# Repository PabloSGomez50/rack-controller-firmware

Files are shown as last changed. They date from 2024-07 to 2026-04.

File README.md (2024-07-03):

# Sistema de Monitoreo y Control IoT para Rack de Telecomunicaciones

Este repositorio contiene el código fuente y la documentación para un dispositivo de monitoreo y control desarrollado para un proveedor de internet. El dispositivo se diseñó para ser instalado en un rack de telecomunicaciones Huawei y se comunica a través de Ethernet para monitorear condiciones ambientales y controlar componentes del rack.

https://github.com/nicolasottone/rack-controller-firmware/assets/64184394/97a96b82-3d05-4193-a270-a76540e8a40f

## Resumen

Se consume la API REST de Google Firebase desde el microcontrolador ESP32 para enviar y recibir datos mediante HTTPS. Desde una aplicación web se accede a los mismos en tiempo real y se controla el dispositivo a distancia. 

**Características:**

* **Monitoreo:**
    * Temperatura ambiental y de contacto.
    * Humedad relativa.
    * Presencia de humo.
    * Estado de la puerta del rack (abierta/cerrada).
* **Control:**
    * 3 ventiladores con control PWM y tacometría.
    * Un relé para control remoto de periféricos.
    * Buzzer para alertas locales.
* **Comunicación:**
    * Conexión Ethernet a través de un módulo ENC28J60.
    * Interfaz web para monitoreo y control remoto.
* **Integración con Firebase:**
    * Envío de datos a la Realtime Database de Firebase.
    * Uso del SDK de Firebase en el lado del cliente para recibir y enviar datos.
    * Conección en tiempo real por Websockets.
    * Autenticación de usuarios con Firebase Auth.
* **Interfaz de Usuario:**
    * Aplicación web con gráficos de datos en tiempo real, KPIs, alertas graficas y panel de configuración.
    * Control remoto de ventiladores, relé y configuración del dispositivo.
* **Hardware:**
    * Microcontrolador ESP32 con RTOS.
    * Modulo Ethernet ENC28J60.
    * Sensores de temperatura, humedad, humo y switch magnético.
    * * Sensor NTC 10K de alta precisión.
    * * Termohigrómetro WS302A1T4
    * * Sensor de Humo JTY-GD-S839
    * Protección contra polaridad inversa.
    * Etapas de acondicionamiento de señales (etapa de potencias, opto-acopladores, etc).
    * Pantalla LCD de 2x16 caracteres.
    * Fuente Step-Up de 48V, fuente Step-Down 12V y reguladores lineales 5V.
    * Conectores HOWSING.

**Arquitectura:**

* **Hardware:**
    * El hardware se basa en el ESP32, un microcontrolador de doble núcleo y ADC incorporados.
    * El módulo ENC28J60 proporciona la conectividad Ethernet.
    * Los sensores, actuadores y periféricos se conectan al ESP32 a través de interfaces GPIO.
* **Software:**
    * El software se divide en dos tareas principales, una para cada núcleo del ESP32:
        * **Núcleo 0:** Lee datos de los sensores, controla los actuadores y maneja los estados del dispositivo.
        * **Núcleo 1:** Envía y recibe datos al servidor a través de una conexión HTTPS.
    * La comunicación con el servidor se realiza mediante peticiones POST y GET a la API REST de Firebase.
    * La aplicación web utiliza WebSockets para recibir actualizaciones de datos en tiempo real.
    * La interfaz de usuario se desarrolló con HTML, CSS, JavaScript y jQuery.

**Calibración:**

* Los ADC fueron calibrados digitalmente usando un multímetro como referencia.
* El termistor NTC se calibró usando el método Steinhart-Hart.
* Se realizaron pruebas de funcionamiento de los ventiladores y se ajustó el control PWM para un óptimo desempeño.

**Niveles de Tensión:**

* El dispositivo opera internamente a 4 niveles de tensión: 48V, 12V, 5V y 3,3V.
* Se puede alimentar con un rango de tensión de 12V a 30V.

**Case:**

* Se diseño un case que consta de dos partes unidas por tornillos para proteger el dispotivo.
* Se utilizo SolidWorks y se diseño para ser impreso en 3D. 

**Documentación:**

* Este README.md proporciona una descripción general del proyecto.
* Los archivos de código fuente contienen comentarios detallados en español.
* La documentación adicional se encuentra en la carpeta `assets`. (Tambien se puede acceder al video con la calidad original).

## Assets:
### Esquema del circuito:
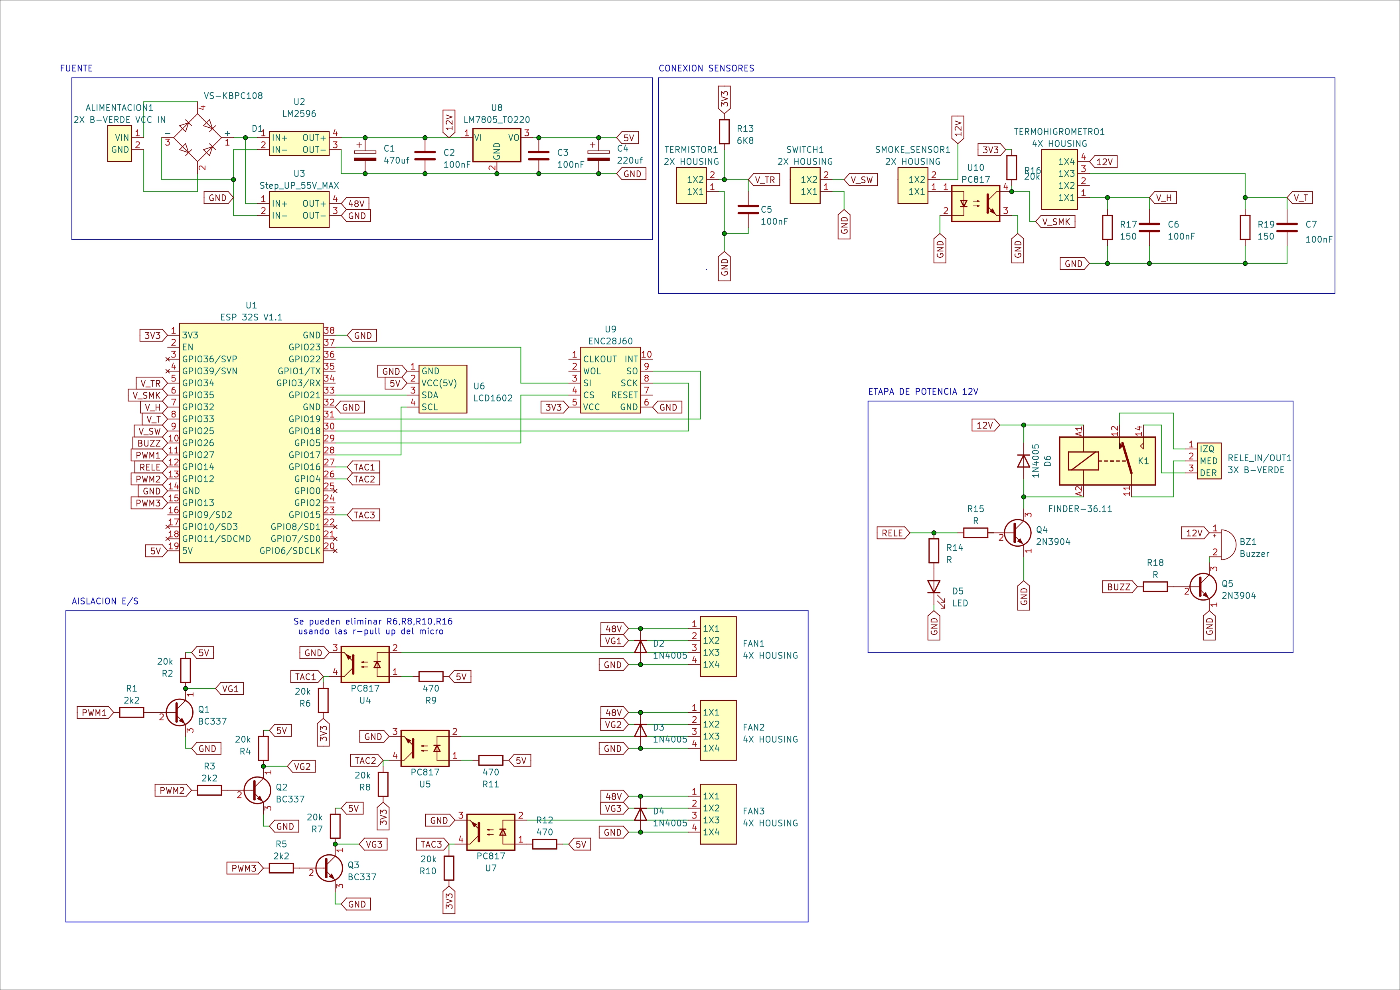
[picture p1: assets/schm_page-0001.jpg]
schm_page-0001
* 

### Imagenes del case:
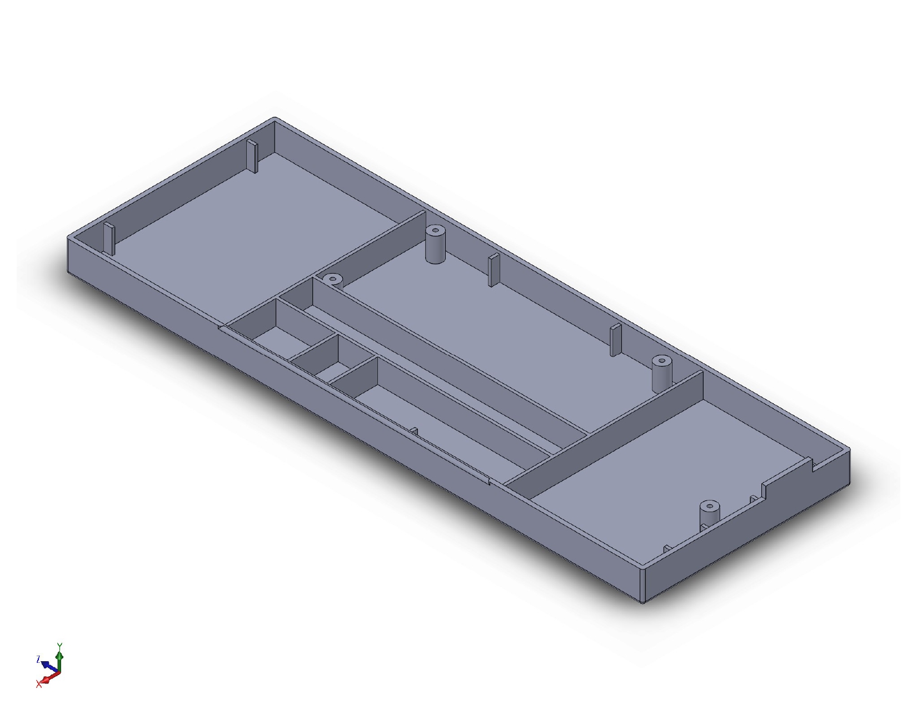
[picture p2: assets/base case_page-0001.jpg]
base case view_page-0001
* 
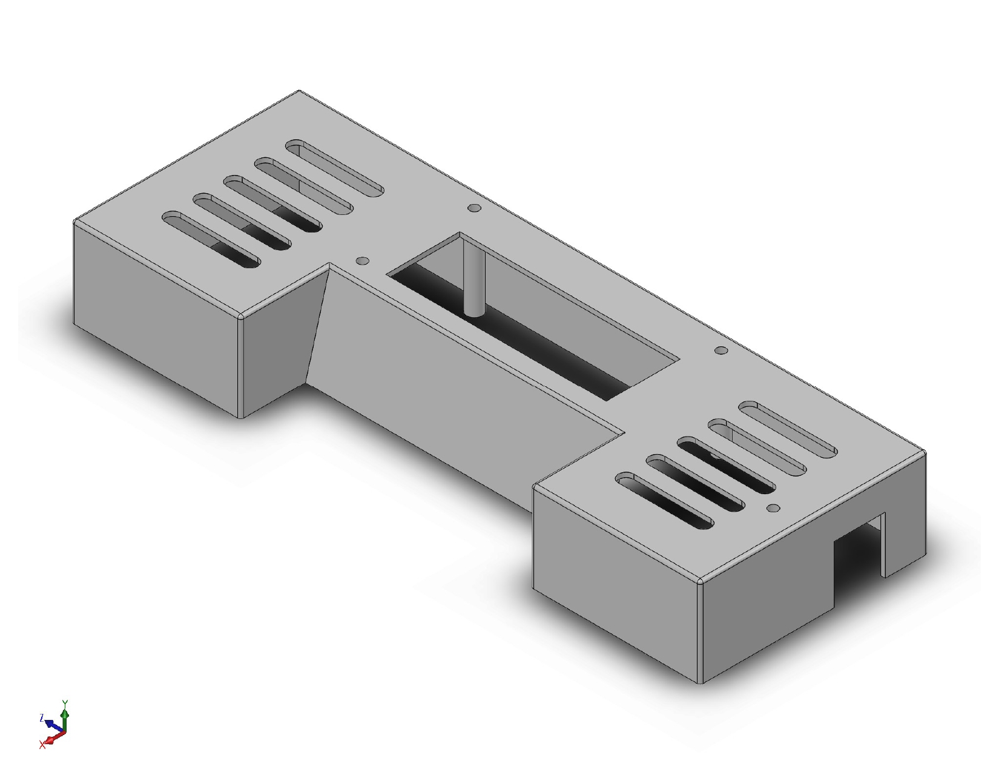
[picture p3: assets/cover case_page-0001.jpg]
cover case_page-0001
* 
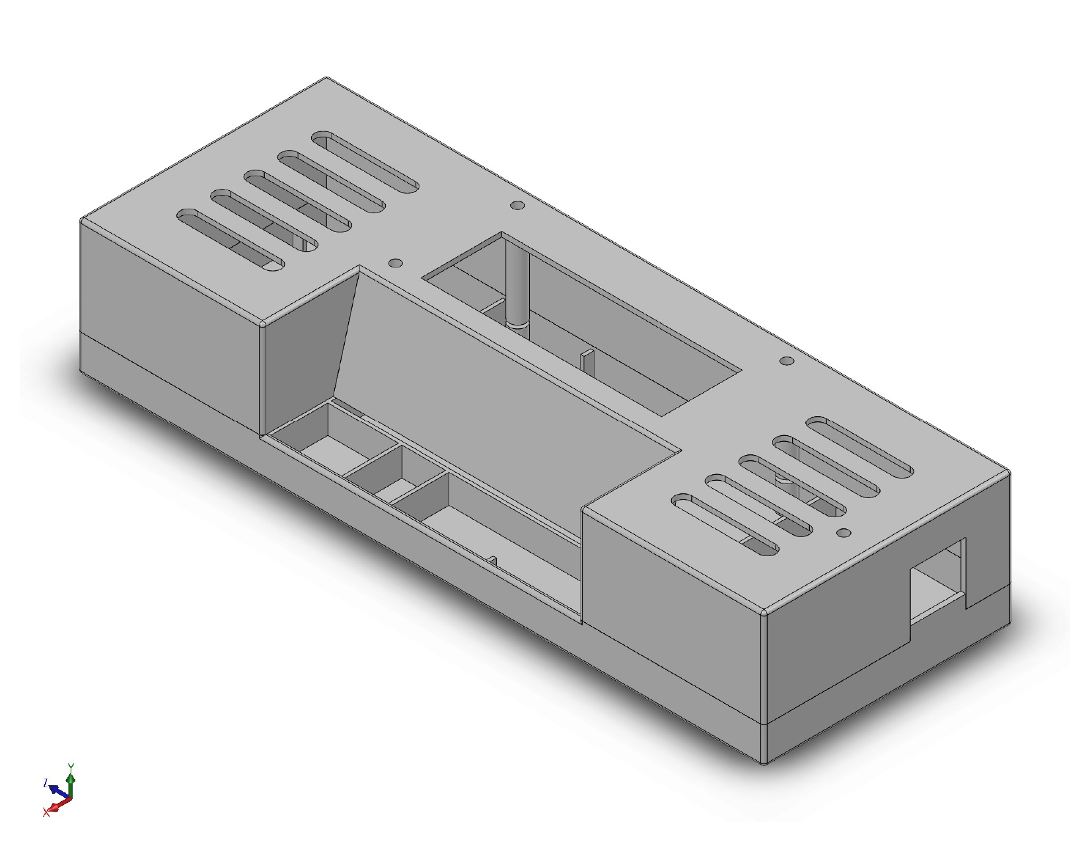
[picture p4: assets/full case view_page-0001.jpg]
full case view_page-0001
* 

### Board:
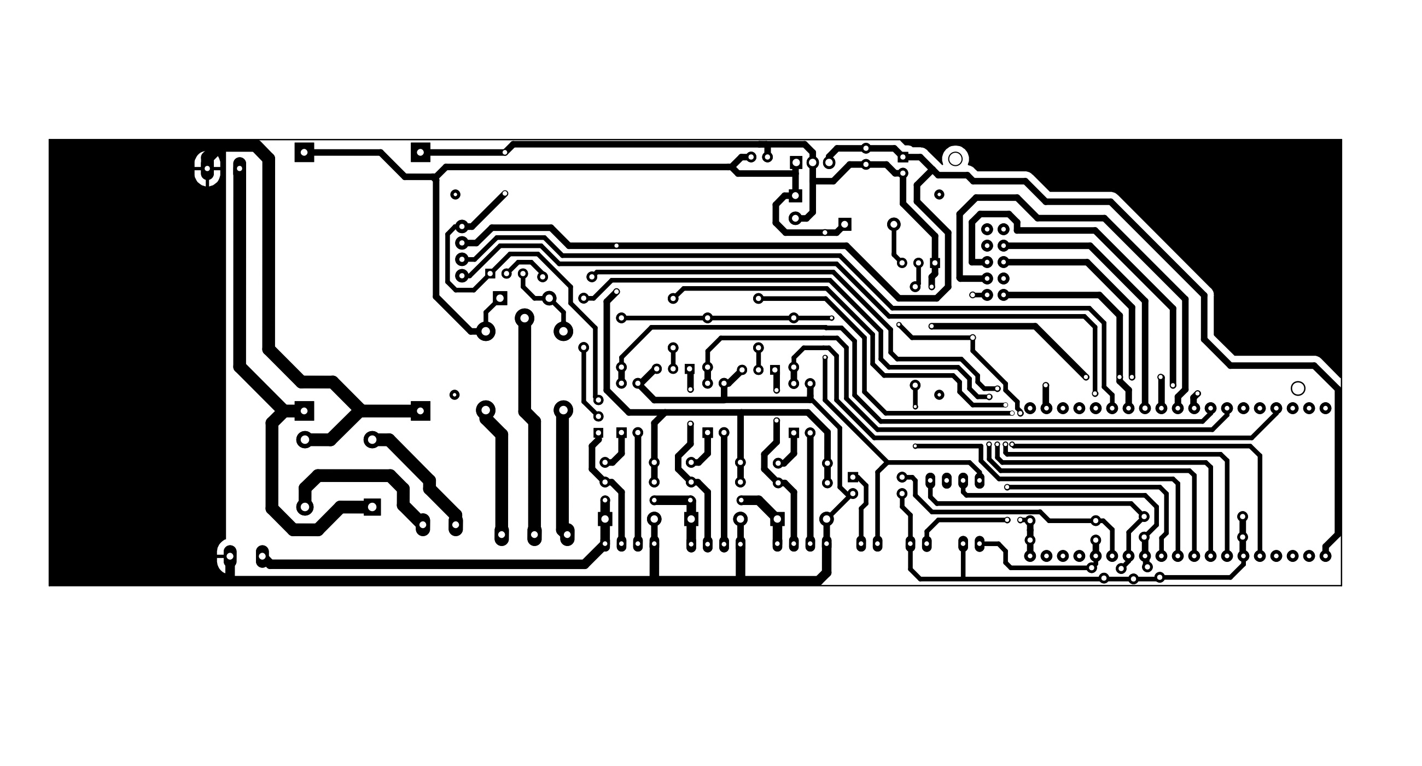
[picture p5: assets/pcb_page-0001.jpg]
pcb_page-0001
* 
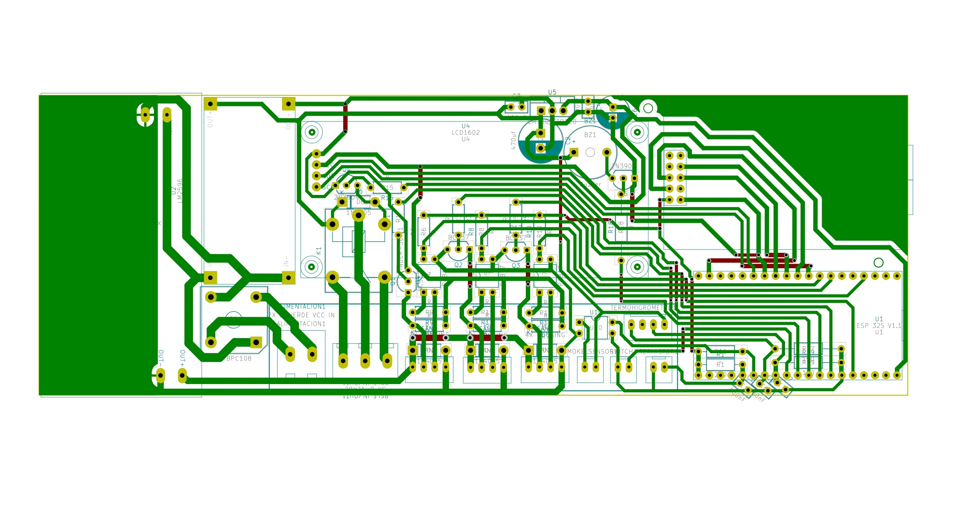
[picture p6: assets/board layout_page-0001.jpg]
board layout_page-0001
*

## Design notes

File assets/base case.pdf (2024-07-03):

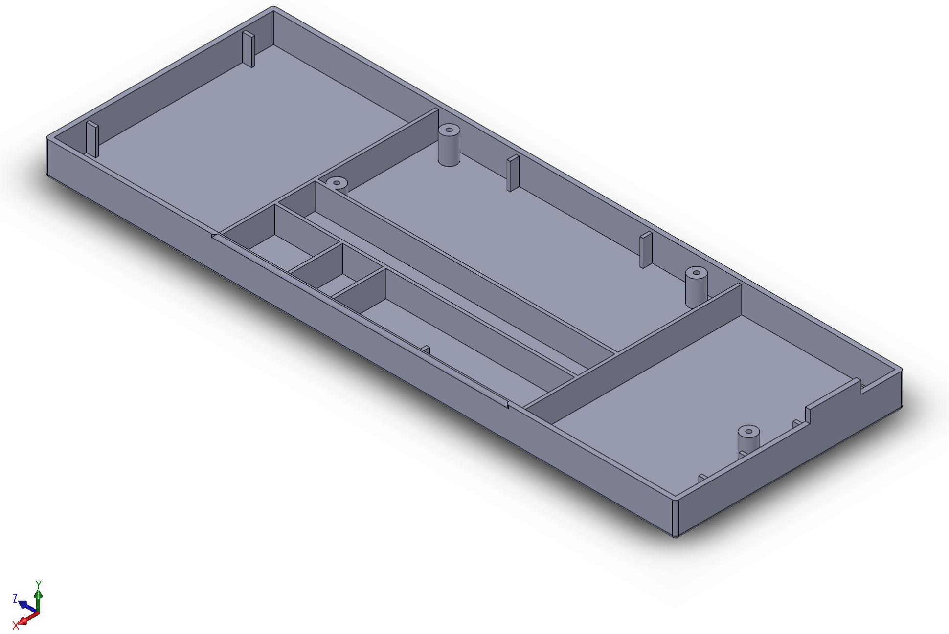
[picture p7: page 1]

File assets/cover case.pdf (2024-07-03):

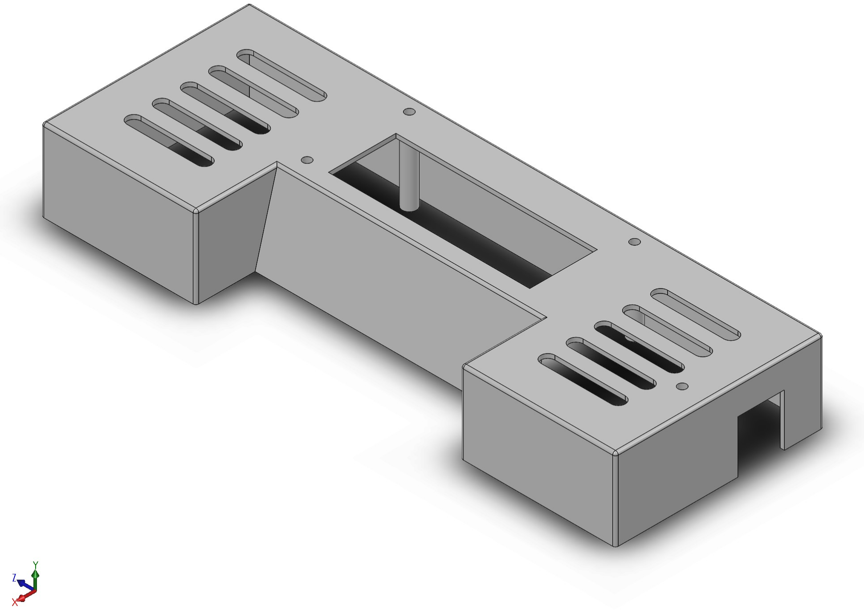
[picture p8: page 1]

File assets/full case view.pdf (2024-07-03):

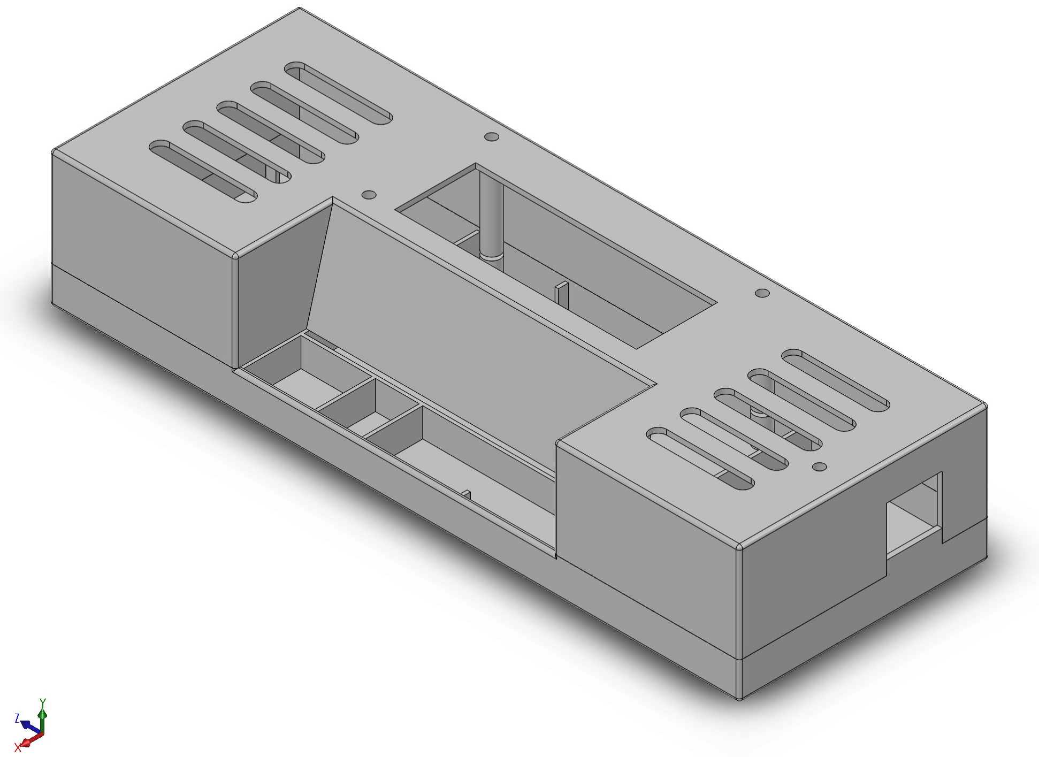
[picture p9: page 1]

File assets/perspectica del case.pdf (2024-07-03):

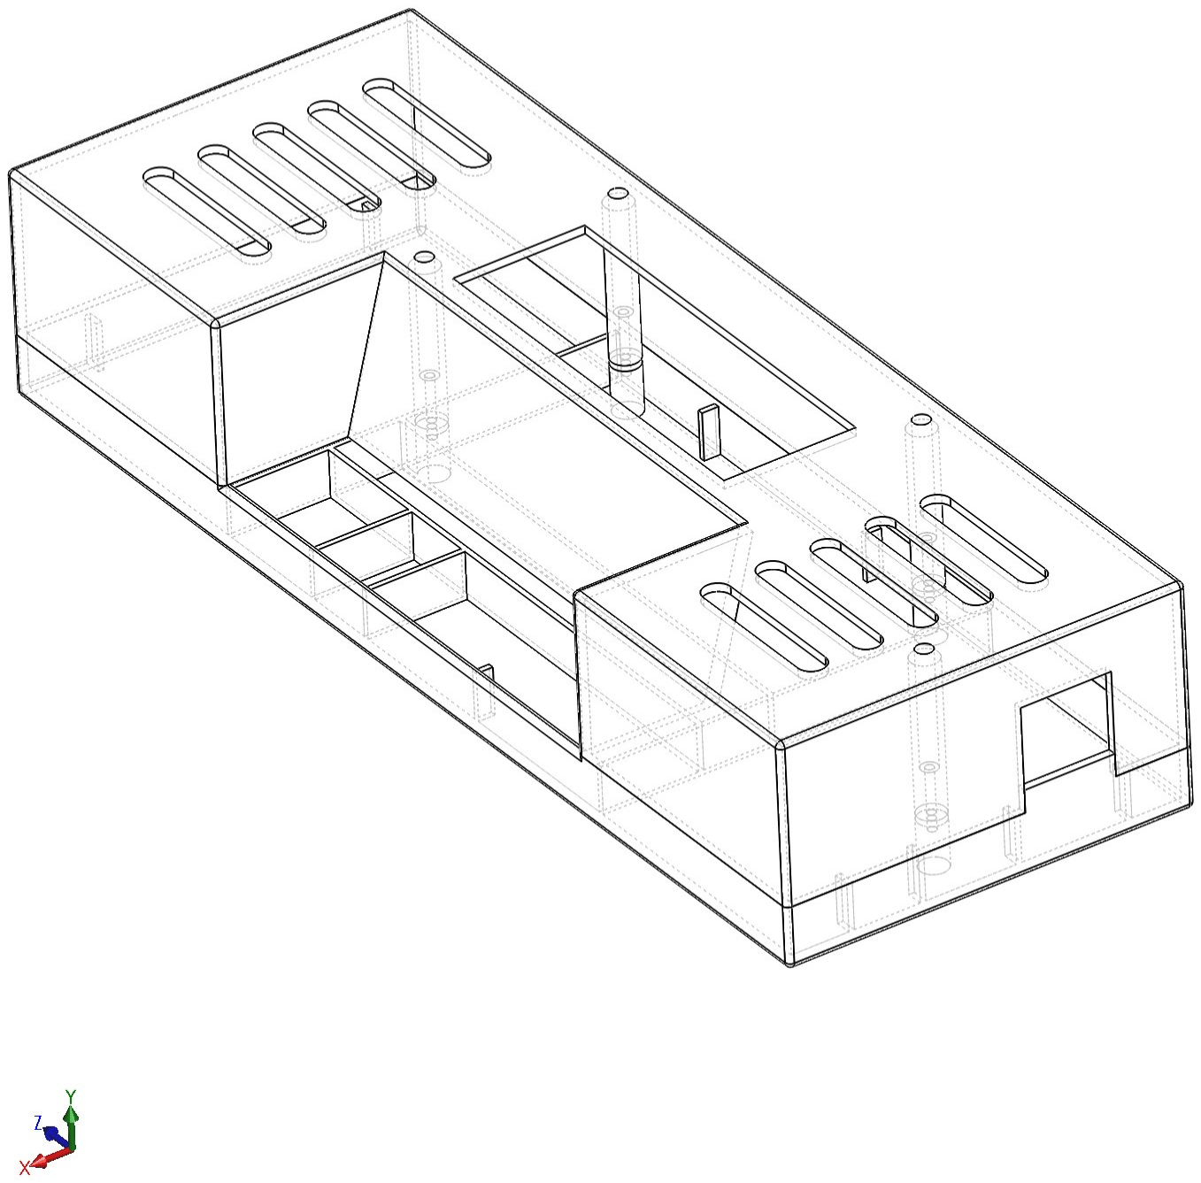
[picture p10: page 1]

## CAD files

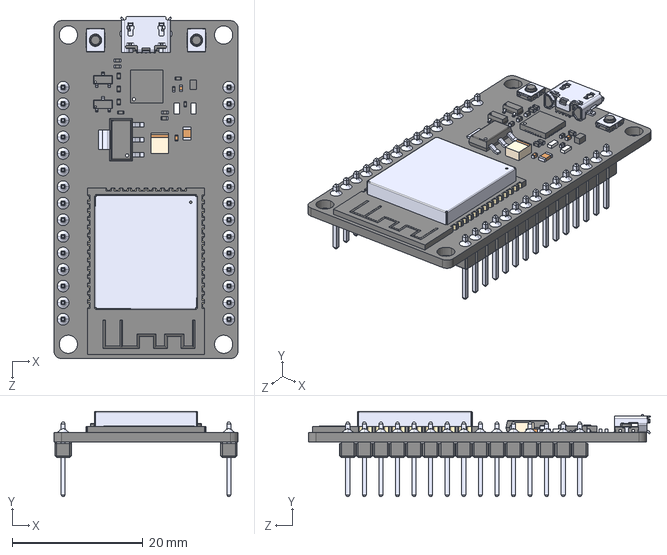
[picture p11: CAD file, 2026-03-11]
rack_monitor_pcb/ESP32-DEVKIT-V1/ESP32-DEVKIT-V1.step
28.2 x 13.1 x 52.5 mm

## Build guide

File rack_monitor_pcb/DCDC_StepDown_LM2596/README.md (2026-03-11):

KiCad library for the LM2596 buck/step-down module

3D models come in two formats : STEP and WRL, in a ZIP archive, files being too large for GitHub.

3D models : bare module, and model with pin headers



Symbol :



Footprint :



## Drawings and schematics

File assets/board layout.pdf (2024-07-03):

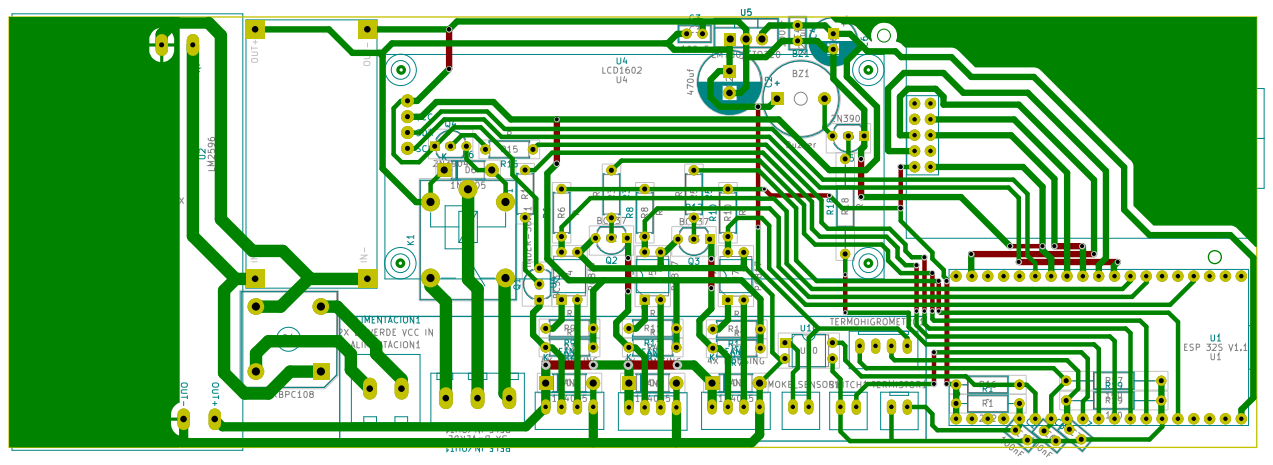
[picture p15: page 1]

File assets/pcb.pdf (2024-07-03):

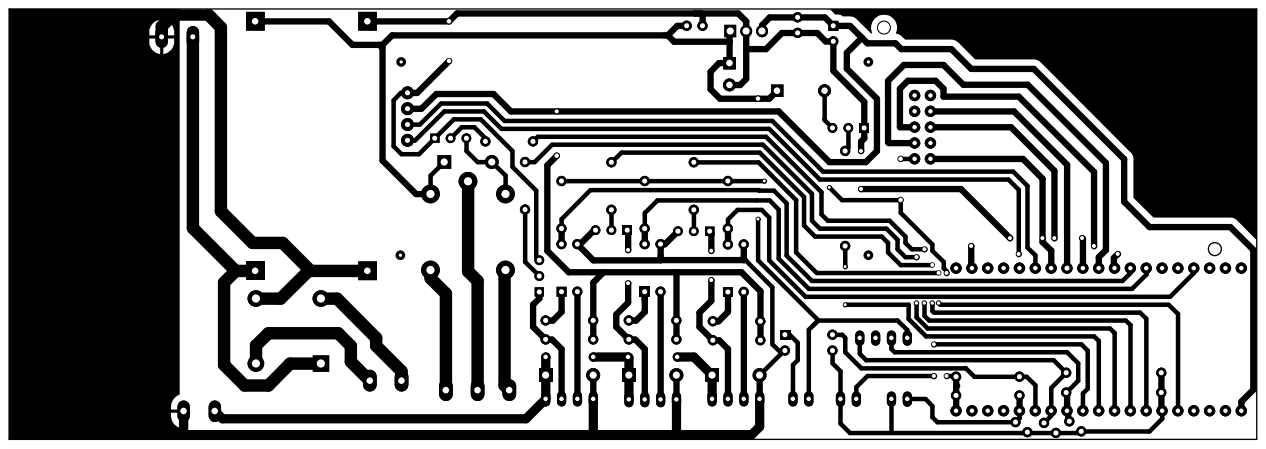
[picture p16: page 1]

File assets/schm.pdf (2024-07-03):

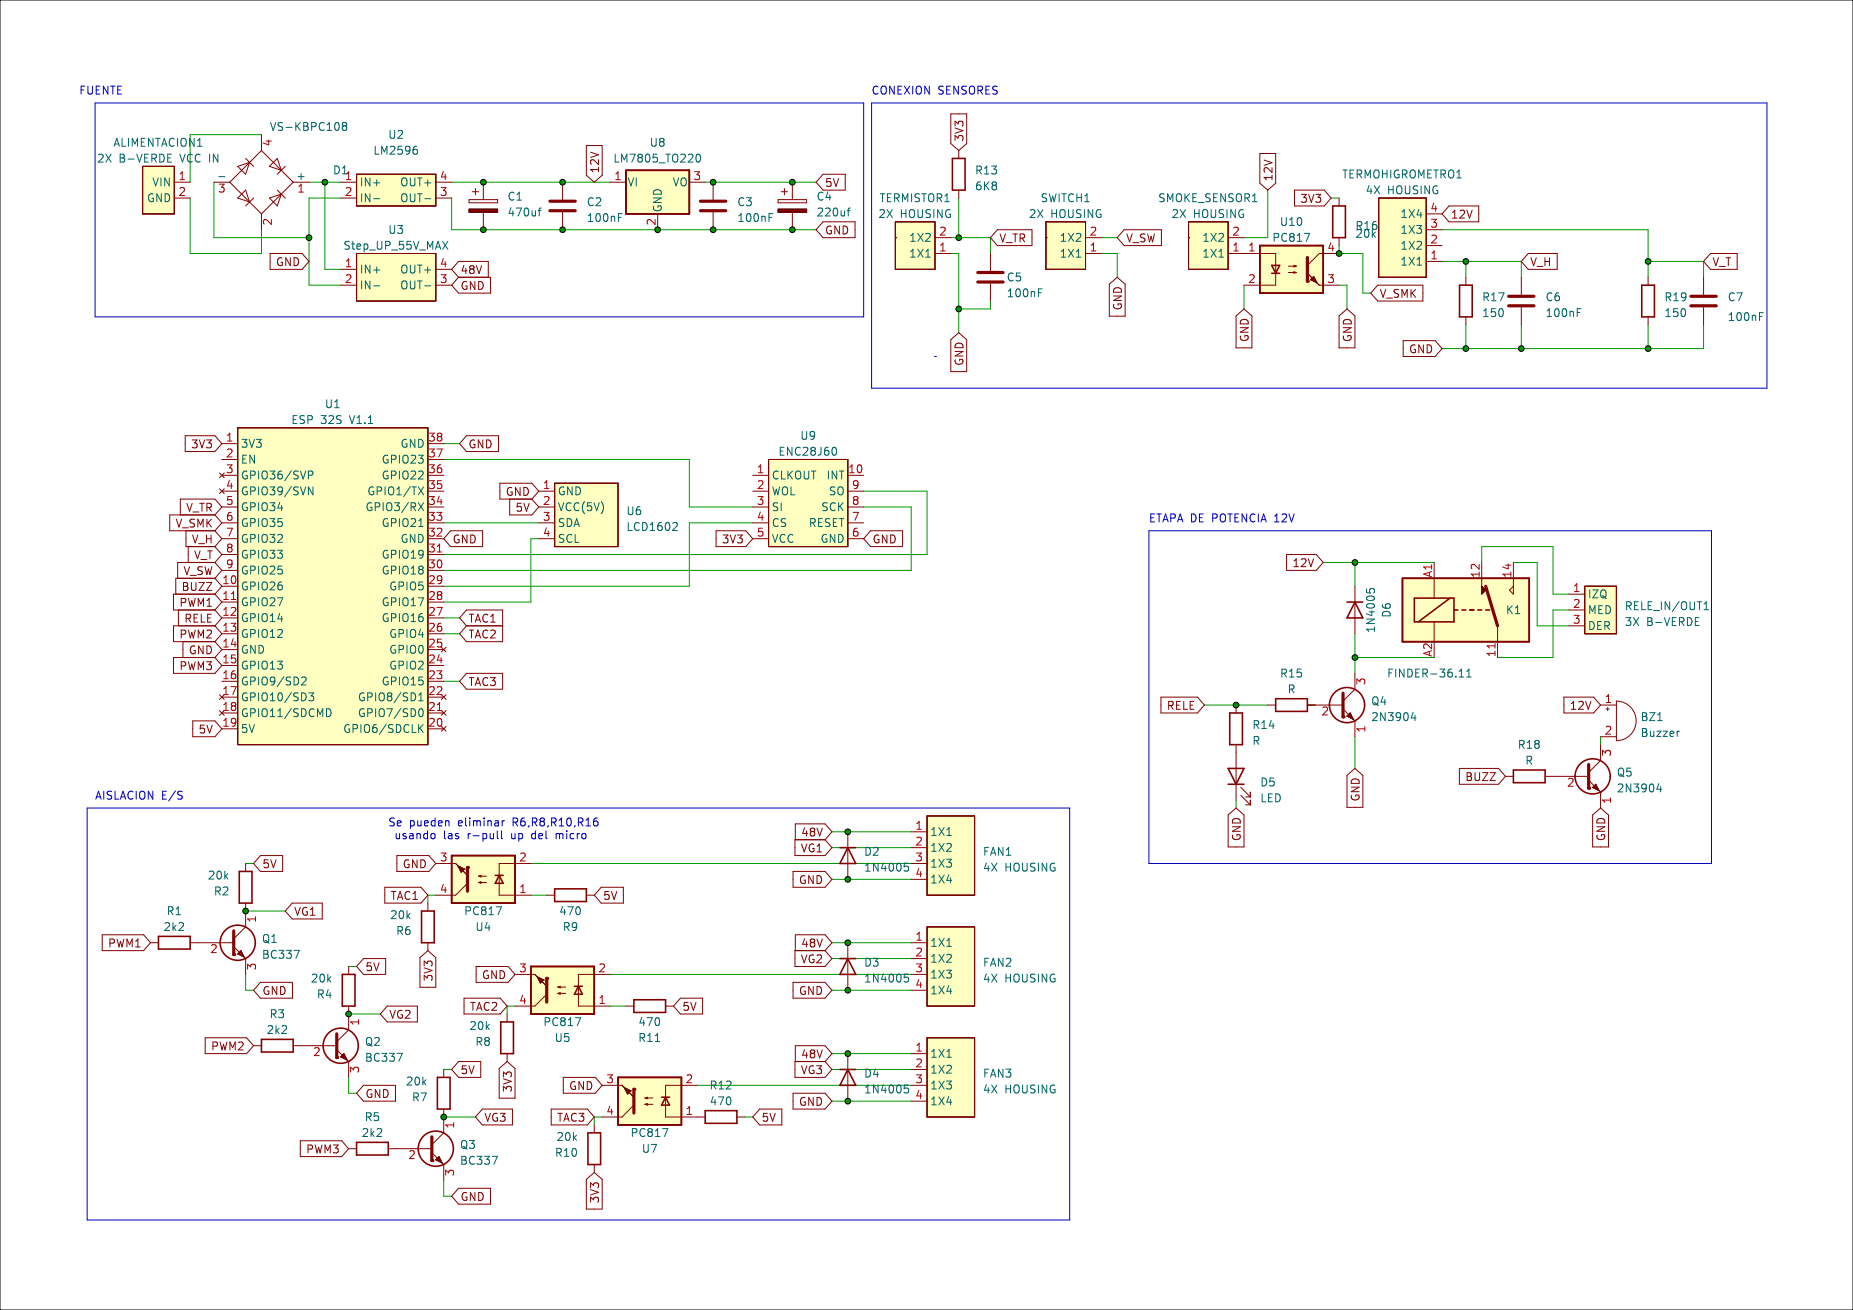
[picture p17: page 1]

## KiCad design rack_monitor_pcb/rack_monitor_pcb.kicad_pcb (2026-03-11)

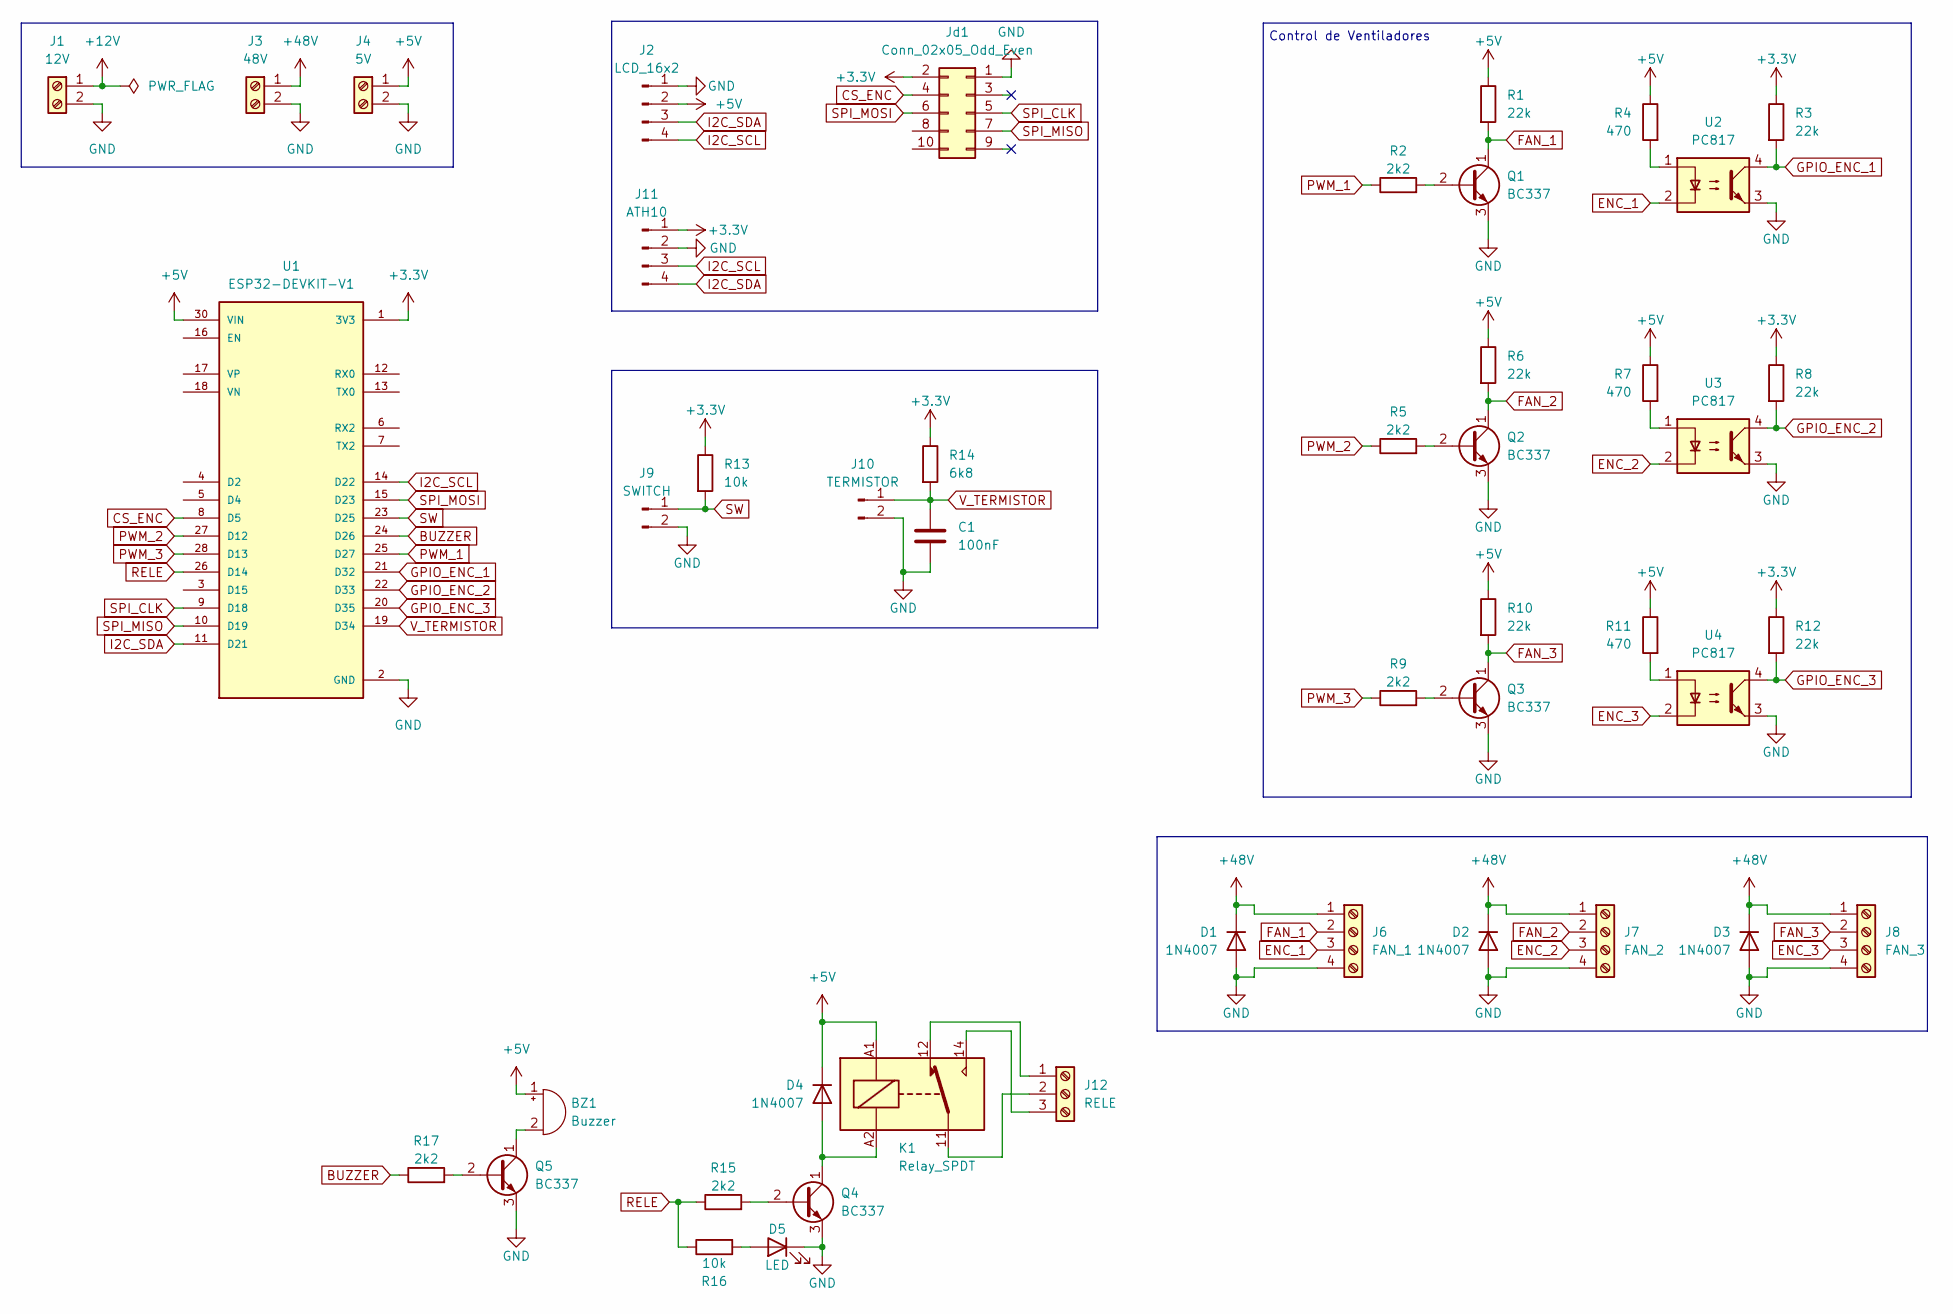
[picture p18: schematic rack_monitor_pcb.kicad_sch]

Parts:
BZ1: Buzzer; Buzzer_12x9.5RM7.6
C1: 100nF; C_Disc_D3.4mm_W2.1mm_P2.50mm
D1, D2, D3, D4: 1N4007; D_DO-41_SOD81_P10.16mm_Horizontal
D5: LED; LED_D3.0mm
J1: 12V; TerminalBlock_Phoenix_MKDS-1,5-2-5.08_1x02_P5.08mm_Horizont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
J2: LCD_16x2; PinHeader_1x04_P2.54mm_Vertical
J3: 48V; TerminalBlock_Phoenix_MKDS-1,5-2-5.08_1x02_P5.08mm_Horizont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
J4: 5V; TerminalBlock_Phoenix_MKDS-1,5-2-5.08_1x02_P5.08mm_Horizont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
J6: FAN_1; Molex_KK-254_AE-6410-04A_1x04_P2.54mm_Vertical
J7: FAN_2; Molex_KK-254_AE-6410-04A_1x04_P2.54mm_Vertical
J8: FAN_3; Molex_KK-254_AE-6410-04A_1x04_P2.54mm_Vertical
J9: SWITCH; Molex_KK-254_AE-6410-02A_1x02_P2.54mm_Vertical
J10: TERMISTOR; Molex_KK-254_AE-6410-02A_1x02_P2.54mm_Vertical
J11: ATH10; PinHeader_1x04_P2.54mm_Vertical
J12: RELE; TerminalBlock_Phoenix_MKDS-1,5-3-5.08_1x03_P5.08mm_Horizont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
Jd1: Conn_02x05_Odd_Even; PinHeader_2x05_P2.54mm_Vertical
K1: Relay_SPDT; Relay_SPDT_Hongfa_HF3F-L-xx-1ZL1T
Q1, Q2, Q3, Q4, Q5: BC337; TO-92_Inline_Wide
R1, R3, R6, R8, R10, R12: 22k; R_Axial_DIN0207_L6.3mm_D2.5mm_P10.16mm_Horizontal
R2, R5, R9, R15, R17: 2k2; R_Axial_DIN0207_L6.3mm_D2.5mm_P10.16mm_Horizontal
R4, R7, R11: 470; R_Axial_DIN0207_L6.3mm_D2.5mm_P10.16mm_Horizontal
R13, R16: 10k; R_Axial_DIN0207_L6.3mm_D2.5mm_P10.16mm_Horizontal
R14: 6k8; R_Axial_DIN0207_L6.3mm_D2.5mm_P10.16mm_Horizontal
U1: ESP32-DEVKIT-V1; MODULE_ESP32_DEVKIT_V1; PARTREV N/A
U2, U3, U4: PC817; DIP-4_W7.62mm

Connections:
+3.3V: J11.1, Jd1.2, R3.1, R8.1, R12.1, R13.1, R14.1, U1.1 (3V3)
+5V: BZ1.1 (+), D4.1 (K), J2.2, J4.1, K1.A1, R1.1, R4.1, R6.1, R7.1, R10.1, R11.1, U1.30 (VIN)
+12V: J1.1
+48V: D1.1 (K), D2.1 (K), D3.1 (K), J3.1, J6.1, J7.1, J8.1
BUZZER: R17.1, U1.24 (D26)
CS_ENC: Jd1.4, U1.8 (D5)
ENC_1: J6.3, U2.2
ENC_2: J7.3, U3.2
ENC_3: J8.3, U4.2
FAN_1: J6.2, Q1.1 (C), R1.2
FAN_2: J7.2, Q2.1 (C), R6.2
FAN_3: J8.2, Q3.1 (C), R10.2
GND: C1.2, D1.2 (A), D2.2 (A), D3.2 (A), D5.1 (K), J1.2, J2.1, J3.2, J4.2, J6.4, J7.4, J8.4, J9.2, J10.2, J11.2, Jd1.1, Q1.3 (E), Q2.3 (E), Q3.3 (E), Q4.3 (E), Q5.3 (E), U1.2 (GND), U1.29 (GND), U2.3, U3.3, U4.3
GPIO_ENC_1: R3.2, U1.21 (D32), U2.4
GPIO_ENC_2: R8.2, U1.22 (D33), U3.4
GPIO_ENC_3: R12.2, U1.20 (D35), U4.4
I2C_SCL: J2.4, J11.3, U1.14 (D22)
I2C_SDA: J2.3, J11.4, U1.11 (D21)
unnamed: BZ1.2 (-), Q5.1 (C)
unnamed: D4.2 (A), K1.A2, Q4.1 (C)
unnamed: D5.2 (A), R16.2
unnamed: J12.1, K1.12
unnamed: J12.2, K1.11
unnamed: J12.3, K1.14
unnamed: Q1.2 (B), R2.2
unnamed: Q2.2 (B), R5.2
unnamed: Q3.2 (B), R9.2
unnamed: Q4.2 (B), R15.2
unnamed: Q5.2 (B), R17.2
unnamed: R4.2, U2.1
unnamed: R7.2, U3.1
unnamed: R11.2, U4.1
PWM_1: R2.1, U1.25 (D27)
PWM_2: R5.1, U1.27 (D12)
PWM_3: R9.1, U1.28 (D13)
RELE: R15.1, R16.1, U1.26 (D14)
SPI_CLK: Jd1.5, U1.9 (D18)
SPI_MISO: Jd1.7, U1.10 (D19)
SPI_MOSI: Jd1.6, U1.15 (D23)
SW: J9.1, R13.2, U1.23 (D25)
V_TERMISTOR: C1.1, J10.1, R14.2, U1.19 (D34)

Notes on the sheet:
Control de Ventiladores

Board: 2 copper layers, 46 parts (0 on the bottom side), 40 nets, no tracks yet.

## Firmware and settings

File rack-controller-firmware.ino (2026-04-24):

#include "driver/gpio.h"
#include "global_variables.h"
#include "connection.h"
// #include <FirebaseJson.h>
#include "data_parser.h"
#include "lcd_display.h"
#include "control.h"
#include "measure.h"
#include "telegram.h"

#ifndef TELEGRAM_BOT_TOKEN
#define TELEGRAM_BOT_TOKEN "7507194258:AAFdjD982tgmD5K9XHtpd24d5Y5sxAWf1d4"
#endif

#ifndef TELEGRAM_ALLOWED_CHAT_ID
#define TELEGRAM_ALLOWED_CHAT_ID "7164870276"
#endif

TaskHandle_t handle_display_task;
TaskHandle_t handle_server_com;      // Inicializo la tarea
SemaphoreHandle_t sem_global_vars;  // Inicializo los semáforos
QueueHandle_t queue_sensor_data;
QueueHandle_t queue_fans_data;
SemaphoreHandle_t sem_network;
TaskHandle_t handle_telegram_task;
sensor_data_t latest_sensor_data;

void task_get_measures(void *parameter);
void task_maintain_connection(void *parameter);
void task_control_fans(void *parameter);
void task_display(void *parameter);
void task_server_com(void *parameter);
void task_telegram(void *parameter);

void setup() {
  setupPinsMode();
  initDisplayCommunication();
  fansInit();
  setDefaultConfig();
  Serial.begin(115200);  // debug

  sem_global_vars = xSemaphoreCreateMutex();  // creo el semáforo para el uso de las variables
  if (sem_global_vars == NULL) {
      Serial.println("Error: No se pudo crear el mutex global");
      while(1); // No sigas si falla
  }
  sem_network = xSemaphoreCreateMutex();
  if (sem_network == NULL) {
    Serial.println("Error: No se pudo crear sem_network");
    while (1);
  }
  queue_sensor_data = xQueueCreate(10, sizeof(sensor_data_t)); // creo la cola para enviar datos de sensores entre tareas
  if (queue_sensor_data == NULL) {
    Serial.println("Error: No se pudo crear queue_sensor_data (heap insuficiente).");
  }
  queue_fans_data = xQueueCreate(1, sizeof(fans_data_t)); // creo la cola para enviar datos de sensores entre tareas
  if (queue_fans_data == NULL) {  
    Serial.println("Error: No se pudo crear queue_fans_data (heap insuficiente).");
  }
  Serial.println("Inicializando Ethernet");
  vTaskDelay(1500 / portTICK_PERIOD_MS);
  ethernetSetup();
  
  dhcpInit();
  latest_sensor_data = {0};
  telegramInit(TELEGRAM_BOT_TOKEN, TELEGRAM_ALLOWED_CHAT_ID);
  // Log free heap to help debug memory-related asserts when using Ethernet
  Serial.print("Free heap after network init: ");
  Serial.println(ESP.getFreeHeap());

  if (!isWifiConnected()) {
    // no hago nada si hay error de hardware
    while (hardwareCheck() == 0) {
      Serial.println("No se encontró el modulo Ethernet.");
      xSemaphoreTake(sem_global_vars, portMAX_DELAY);
      module_error = true;
      xSemaphoreGive(sem_global_vars);
      vTaskDelay(5000 / portTICK_PERIOD_MS);
    }
    while (wireIsConnected() == 0) {
      Serial.println("El cable Ethernet no está conectado. Conectalo por favor");
      xSemaphoreTake(sem_global_vars, portMAX_DELAY);
      wire_error = true;
      xSemaphoreGive(sem_global_vars);
      vTaskDelay(2000 / portTICK_PERIOD_MS);
    }
  }

  Serial.println("Inicio de tareas");
  
  xTaskCreatePinnedToCore(
    task_server_com,
    "task_server_com",
    RTOS_MINIMAL_STACKSIZE * 32,
    NULL,
    0,
    &handle_server_com,
    1 // Core ID (evita competir con tareas internas de WiFi/IDLE0)
  );
  vTaskSuspend(handle_server_com); // Empiezo la tarea suspendida, se activará al conectar con éxito Ethernet o WiFi
  xTaskCreatePinnedToCore(
    task_telegram,
    "task_telegram",
    RTOS_MINIMAL_STACKSIZE * 48,
    NULL,
    0,
    &handle_telegram_task,
    1 // Core ID
  );
  vTaskSuspend(handle_telegram_task);
  xTaskCreatePinnedToCore(
    task_maintain_connection,
    "task_maintain_connection",
    RTOS_MINIMAL_STACKSIZE * 8,
    NULL,
    0,
    NULL,
    1 // Core ID
  );
  xTaskCreatePinnedToCore(
    task_control_fans,
    "task_control_fans",
    RTOS_MINIMAL_STACKSIZE * 8,
    NULL,
    0,
    NULL,
    0 // Core ID
  );
  xTaskCreatePinnedToCore(
    task_display,
    "task_display",
    RTOS_MINIMAL_STACKSIZE * 8,
    NULL,
    0,
    &handle_display_task,
    0 // Core ID
  );
  xTaskCreatePinnedToCore(
    task_get_measures,
    "task_get_measures",
    RTOS_MINIMAL_STACKSIZE * 16,
    NULL,
    0,
    NULL,
    0 // Core ID
  );
}

void task_control_fans(void *parameter) {
  fans_data_t fans_data;
  while (true) {
    
      fans_data.rpm_fan1 = getFanSpeed(1);
      fans_data.rpm_fan2 = getFanSpeed(2);
      fans_data.rpm_fan3 = getFanSpeed(3);
      fans_data.speed = speed;
      if (queue_fans_data != NULL) {
        xQueueOverwrite(queue_fans_data, &fans_data);
      } else {
        Serial.println("Warning: queue_fans_data is NULL (skipping overwrite)");
      }
      speed = (is_automatic_speed) ? getDynamicSpeed(hum, temp, temp_tmr) : manual_speed;
      setAllFanSpeed(speed);
      vTaskDelay(FAN_PERIOD / portTICK_PERIOD_MS);
  }
}

void task_display(void *parameter) {
  displayInit();
  uint8_t display_seq = 0;
  fans_data_t fans_data = {0};
  while (true) {

    displayOn();
    while (digitalRead(SWITCH_PIN)) {
      switch (display_seq) {
        case 0:
          printErrors(); // Fila 0
          printMeasures(); // Fila 1
          break;
        case 1:
          if (queue_fans_data != NULL) {
            xQueuePeek(queue_fans_data, &fans_data, 0);
          }
          printFanStatus(fans_data); // Fila 0 y 1
          break;
        // case 2:
        //   printRedStatus(); // Fila 0
        //   break;
      }
      display_seq = (display_seq + 1) % 2;
      vTaskDelay(2000 / portTICK_PERIOD_MS);
    }
    
    displayOff();
    ulTaskNotifyTake(pdTRUE, portMAX_DELAY);   // wait for door event
    vTaskDelay(pdMS_TO_TICKS(50));
  }
}

// Núcleo 0
void task_get_measures(void *parameter) {
  sensor_data_t sensor_data;
  // sensor_data_t *sensor_max = (sensor_data_t *) parameter;
  uint8_t measure_seq = 0;
  while (true) {
      //tomo medidas y checkeo estados cada 1 segundo
      sensor_data.temp = get_temp();
      sensor_data.temp_tmr = get_temp_tmr();
      sensor_data.hum = get_hum();
      sensor_data.smoke = !digitalRead(SMK_PIN);
      sensor_data.door_open = digitalRead(SWITCH_PIN);
      xSemaphoreTake(sem_global_vars, portMAX_DELAY);
      check_hum();
      check_temp();
      // check_smk_sensor();
      xSemaphoreGive(sem_global_vars);
      
      if (sensor_data.smoke || crit_temp_flag || crit_temp_tmr_flag)
        digitalWrite(BUZZER, 1);
      else
        digitalWrite(BUZZER, 0);
      
        measure_seq++;
        if (measure_seq >= 2) {
          measure_seq = 0;
          if (queue_sensor_data != NULL) {
            xQueueSend(queue_sensor_data, &sensor_data, 100 / portTICK_PERIOD_MS);
          } else {
            Serial.println("Error: queue_sensor_data no creada");
          }
        }
      vTaskDelay(500 / portTICK_PERIOD_MS);
  }
}


void task_server_com(void *parameter) {

  sensor_data_t sensor_data;
  fans_data_t fans_data;
  uint8_t config_cycles_wait = 3, config_cycle = 0;
  while (true) {
    if (queue_sensor_data == NULL) {
      // Cola no creada: evitar llamar a API de cola con NULL (provoca assert)
      vTaskDelay(1000 / portTICK_PERIOD_MS);
      continue;
    }

    if (xQueueReceive(queue_sensor_data, &sensor_data, portMAX_DELAY) == pdTRUE) {
      xSemaphoreTake(sem_global_vars, portMAX_DELAY);
      latest_sensor_data = sensor_data;
      xSemaphoreGive(sem_global_vars);

      xSemaphoreTake(sem_network, portMAX_DELAY);
      send_sensor_data(sensor_data);
      xSemaphoreGive(sem_network);

      vTaskDelay(10 / portTICK_PERIOD_MS); 

      if (xQueuePeek(queue_fans_data, &fans_data, 0) == pdTRUE) {
        xSemaphoreTake(sem_network, portMAX_DELAY);
        send_fans_data(fans_data);
        xSemaphoreGive(sem_network);
      }

      vTaskDelay(10 / portTICK_PERIOD_MS);

      config_cycle++;
      if (config_cycle >= config_cycles_wait) {
        config_cycle = 0;
        xSemaphoreTake(sem_network, portMAX_DELAY);
        load_data_from_server();
        xSemaphoreGive(sem_network);
      }

      Serial.println("Datos enviados al servidor");
      // Cede CPU para que IDLE0 pueda ejecutar y evitar disparos del task watchdog.
      vTaskDelay(10 / portTICK_PERIOD_MS);
    }
  }
}

void task_telegram(void *parameter) {
  telegram_update_t updates[3];
  sensor_data_t status_snapshot = {0};
  uint16_t diag_counter = 0;
  bool warned_no_wifi = false;
  Serial.println("Inicio de task_telegram");
  vTaskDelay(3000 / portTICK_PERIOD_MS);
  while (true) {
    if (!isWifiConnected()) {
      if (!warned_no_wifi) {
        Serial.println("Telegram deshabilitado en Ethernet (TLS sobre ENC28J60 inestable)");
        warned_no_wifi = true;
      }
      vTaskDelay(5000 / portTICK_PERIOD_MS);
      continue;
    }
    warned_no_wifi = false;

    size_t nupd = 0;
    if (xSemaphoreTake(sem_network, 1500 / portTICK_PERIOD_MS) == pdTRUE) {
      nupd = telegramPollUpdates(updates, 3, 0);
      xSemaphoreGive(sem_network);
    }
    Serial.println("Telegram: " + String(nupd) + " updates");

    for (size_t i = 0; i < nupd; i++) {
      // if (String(TELEGRAM_ALLOWED_CHAT_ID).length() > 0 && updates[i].chat_id != String(TELEGRAM_ALLOWED_CHAT_ID)) {
      //   Serial.println("Telegram: Ignorando mensaje de chat no autorizado: " + String(updates[i].chat_id));
      //   continue;
      // }
      Serial.println("Telegram: Procesando update de chat_id: '" + String(updates[i].chat_id) + "' con texto: " + updates[i].text);

      String cmd, args;
      if (!telegramParseCommand(updates[i], cmd, args)) {
        continue;
      }
      Serial.println("Telegram: Comando recibido: '" + cmd + "' Args: '" + args + "'");

      if (cmd == "/status") {
        xSemaphoreTake(sem_global_vars, portMAX_DELAY);
        status_snapshot = latest_sensor_data;
        float speed_snapshot = speed;
        xSemaphoreGive(sem_global_vars);

        String msg = "Estado rack:\n";
        msg += "Temp: " + String(status_snapshot.temp, 1) + " C\n";
        msg += "Temp TMR: " + String(status_snapshot.temp_tmr, 1) + " C\n";
        msg += "Hum: " + String(status_snapshot.hum) + " %\n";
        msg += "Smoke: " + String(status_snapshot.smoke ? "SI" : "NO") + "\n";
        msg += "Door: " + String(status_snapshot.door_open ? "ABIERTA" : "CERRADA") + "\n";
        msg += "Speed: " + String(speed_snapshot, 2);

        xSemaphoreTake(sem_network, portMAX_DELAY);
        telegramSendMessage(updates[i].chat_id, msg);
        xSemaphoreGive(sem_network);
      } else if (cmd == "/auto") {
        xSemaphoreTake(sem_global_vars, portMAX_DELAY);
        is_automatic_speed = true;
        xSemaphoreGive(sem_global_vars);

        xSemaphoreTake(sem_network, portMAX_DELAY);
        telegramSendMessage(updates[i].chat_id, "Modo automatico activado");
        xSemaphoreGive(sem_network);
      } else if (cmd == "/fans") {
        float newSpeed = args.toFloat();
        if (newSpeed < 0.0f || newSpeed > 1.0f) {
          xSemaphoreTake(sem_network, portMAX_DELAY);
          telegramSendMessage(updates[i].chat_id, "Uso: /fans <valor 0.0 a 1.0>");
          xSemaphoreGive(sem_network);
        } else {
          xSemaphoreTake(sem_global_vars, portMAX_DELAY);
          manual_speed = newSpeed;
          is_automatic_speed = false;
          xSemaphoreGive(sem_global_vars);

          xSemaphoreTake(sem_network, portMAX_DELAY);
          telegramSendMessage(updates[i].chat_id, "Velocidad manual aplicada");
          xSemaphoreGive(sem_network);
        }
      } else if (cmd == "/rele") {
        String a = args;
        a.toLowerCase();
        if (a == "on") {
          xSemaphoreTake(sem_global_vars, portMAX_DELAY);
          rele = true;
          xSemaphoreGive(sem_global_vars);

          xSemaphoreTake(sem_network, portMAX_DELAY);
          telegramSendMessage(updates[i].chat_id, "Rele ON");
          xSemaphoreGive(sem_network);
        } else if (a == "off") {
          xSemaphoreTake(sem_global_vars, portMAX_DELAY);
          rele = false;
          xSemaphoreGive(sem_global_vars);

          xSemaphoreTake(sem_network, portMAX_DELAY);
          telegramSendMessage(updates[i].chat_id, "Rele OFF");
          xSemaphoreGive(sem_network);
        } else {
          xSemaphoreTake(sem_network, portMAX_DELAY);
          telegramSendMessage(updates[i].chat_id, "Uso: /rele on|off");
          xSemaphoreGive(sem_network);
        }
      } else if (cmd == "/buzzer") {
        String a = args;
        a.toLowerCase();
        if (a == "on") {
          xSemaphoreTake(sem_global_vars, portMAX_DELAY);
          buzzer = true;
          xSemaphoreGive(sem_global_vars);

          xSemaphoreTake(sem_network, portMAX_DELAY);
          telegramSendMessage(updates[i].chat_id, "Buzzer habilitado");
          xSemaphoreGive(sem_network);
        } else if (a == "off") {
          xSemaphoreTake(sem_global_vars, portMAX_DELAY);
          buzzer = false;
          xSemaphoreGive(sem_global_vars);

          xSemaphoreTake(sem_network, portMAX_DELAY);
          telegramSendMessage(updates[i].chat_id, "Buzzer deshabilitado");
          xSemaphoreGive(sem_network);
        } else {
          xSemaphoreTake(sem_network, portMAX_DELAY);
          telegramSendMessage(updates[i].chat_id, "Uso: /buzzer on|off");
          xSemaphoreGive(sem_network);
        }
      } else if (cmd == "/help") {
        xSemaphoreTake(sem_network, portMAX_DELAY);
        telegramSendMessage(updates[i].chat_id,
                            "/status\n/auto\n/fans <0..1>\n/rele on|off\n/buzzer on|off");
        xSemaphoreGive(sem_network);
      }
    }

    diag_counter++;
    if (diag_counter >= 30) {
      diag_counter = 0;
      Serial.printf("Telegram stack watermark: %u bytes\n", (unsigned int)uxTaskGetStackHighWaterMark(NULL));
    }

    vTaskDelay(1000 / portTICK_PERIOD_MS);
  }
}

void loop() {
  vTaskDelay(5000 / portTICK_PERIOD_MS);
}


void task_maintain_connection(void *parameter) {
  bool is_connected = false;
  while (true) {
    if (isWifiConnected() || (hardwareCheck() && wireIsConnected())) {
      if (!is_connected) {
        xSemaphoreTake(sem_global_vars, portMAX_DELAY);
        connected = true;
        wire_error = false;
        xSemaphoreGive(sem_global_vars);
        if (handle_server_com != NULL)
          vTaskResume(handle_server_com);
        if (handle_telegram_task != NULL)
          vTaskResume(handle_telegram_task);
        is_connected = true;
      }
    } else {
      xSemaphoreTake(sem_global_vars, portMAX_DELAY);
      connected = false;
      wire_error = true;
      xSemaphoreGive(sem_global_vars);
      if (handle_server_com != NULL)
        vTaskSuspend(handle_server_com);
      if (handle_telegram_task != NULL)
        vTaskSuspend(handle_telegram_task);
      is_connected = false;
    }
    connectionMantain();
    vTaskDelay(200 / portTICK_PERIOD_MS);
  }
}

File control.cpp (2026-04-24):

#include <Arduino.h>
#include "global_variables.h"
#include "driver/gpio.h"
#include "driver/ledc.h"

const int FAN_METER[3] = { FAN1_METER, FAN2_METER, FAN3_METER };  // Pines de los medidores de los ventiladores

// Contadores de pulsos (incrementados en ISR)
volatile uint32_t pulseCounter[3] = {0, 0, 0};
// uint32_t rpm[3] = {0, 0, 0};

// Mutex o Spinlock para proteger la lectura de los contadores
portMUX_TYPE mux = portMUX_INITIALIZER_UNLOCKED;

// ISRs ultra-livianas
void IRAM_ATTR isrFan1() { portENTER_CRITICAL_ISR(&mux); pulseCounter[0]++; portEXIT_CRITICAL_ISR(&mux); }
void IRAM_ATTR isrFan2() { portENTER_CRITICAL_ISR(&mux); pulseCounter[1]++; portEXIT_CRITICAL_ISR(&mux); }
void IRAM_ATTR isrFan3() { portENTER_CRITICAL_ISR(&mux); pulseCounter[2]++; portEXIT_CRITICAL_ISR(&mux); }

void IRAM_ATTR doorInterrupt() {
  if (handle_display_task == nullptr) {
    return;
  }
  static volatile TickType_t last_tick = 0;
  TickType_t now = xTaskGetTickCountFromISR();
  if ((now - last_tick) < pdMS_TO_TICKS(20)) return; // short debounce to avoid floods
  last_tick = now;
  
  BaseType_t hpTaskWoken = pdFALSE;
  vTaskNotifyGiveFromISR(handle_display_task, &hpTaskWoken);
  portYIELD_FROM_ISR(hpTaskWoken);
}

const int frequency = 10000;  // Hz
const int FAN_PIN[3] = { FAN1, FAN2, FAN3 };  // Pines de los ventiladores
const ledc_mode_t speed_mode = LEDC_HIGH_SPEED_MODE;
const ledc_timer_t timer = LEDC_TIMER_0;
const ledc_channel_t channels[3] = { LEDC_CHANNEL_1, LEDC_CHANNEL_2, LEDC_CHANNEL_3 };
const ledc_timer_bit_t duty_resolution = LEDC_TIMER_8_BIT;

void setupPinsMode(void) {
  pinMode(TEMP_PIN, INPUT);
  pinMode(HUM_PIN, INPUT);
  pinMode(TMR_PIN, INPUT);
  pinMode(SWITCH_PIN, INPUT_PULLUP);
  pinMode(SMK_PIN, INPUT);
  pinMode(FAN1, OUTPUT);
  pinMode(FAN1_METER, INPUT);
  pinMode(FAN2, OUTPUT);
  pinMode(FAN2_METER, INPUT);
  pinMode(FAN3, OUTPUT);
  pinMode(FAN3_METER, INPUT);
  pinMode(BUZZER, OUTPUT);
  pinMode(RELE_PIN, OUTPUT);

  attachInterrupt(digitalPinToInterrupt(FAN1_METER), isrFan1, FALLING);
  attachInterrupt(digitalPinToInterrupt(FAN2_METER), isrFan2, FALLING);
  attachInterrupt(digitalPinToInterrupt(FAN3_METER), isrFan3, FALLING);
  attachInterrupt(digitalPinToInterrupt(SWITCH_PIN), doorInterrupt, FALLING);
}

void fansInit() {
  // configure timer
  ledc_timer_config_t ledc_timer = {
    .speed_mode = speed_mode,
    .duty_resolution = duty_resolution,
    .timer_num = timer,
    .freq_hz = frequency,
    .clk_cfg = LEDC_AUTO_CLK
  };
  ledc_timer_config(&ledc_timer);

  // configure channels and attach GPIOs
  for (int i = 0; i < 3; ++i) {
    ledc_channel_config_t ledc_channel = {
      .gpio_num = FAN_PIN[i],
      .speed_mode = speed_mode, 
      .channel = channels[i],
      .intr_type = LEDC_INTR_DISABLE,
      .timer_sel = timer,
      .duty = 0,
      .hpoint = 0
    };
    ledc_channel_config(&ledc_channel);
  }
}

uint32_t getFanSpeed(int fan) {
  noInterrupts();
  uint32_t pulses = pulseCounter[fan - 1];
  pulseCounter[fan - 1] = 0; // Reiniciar el contador
  interrupts();
  return pulses * (60000 / (FAN_PERIOD * FAN_PULSES));
}

float getDynamicSpeed(int hum, float temp, float temp_tmr) {
  const float avr_temp = 25.0f;              // Temperatura promedio y óptima dentro de un rack
  const float avr_hum = 60.0f;               // Humedad promedio en Buenos Aires
  const float max_hum = 90.0f;               // Humedad máxima aceptable
  const float min_speed = 0.3f;              // Velocidad mínima del ventilador
  const float max_speed = 1.0f;              // Velocidad máxima del ventilador
  const float temp_increase_factor = 30.0f;  // Factor de aumento de velocidad por temperatura
  float fan_speed = min_speed;               // Velocidad inicial del ventilador siempre comienza en 0.3

  // Si la humedad es mayor que el máximo aceptable, el ventilador se detiene
  if (hum > max_hum) {
    return 0.0f;
  }

  // Ajuste de la velocidad del ventilador en función de la humedad si está dentro de los umbrales
  if (hum > 0 && hum <= max_hum) {
    float delta_hum = avr_hum - hum;
    if (delta_hum >= 0) {
      fan_speed += (delta_hum / 100.0f) * (min_speed - 0.0f);
    } else {
      fan_speed += (delta_hum / 200.0f) * (min_speed - 0.0f);
    }
  }

  // Ajuste de la velocidad del ventilador en base a la temperatura actual si es superior al promedio
  if (temp > avr_temp) {
    float delta_temp = temp - avr_temp;
    fan_speed += delta_temp / temp_increase_factor;
  }

  // Ajuste de la velocidad del ventilador en función de la temperatura de mañana si es superior al promedio
  if (temp_tmr > avr_temp) {
    float delta_temp_tmr = temp_tmr - avr_temp;
    fan_speed += delta_temp_tmr / (temp_increase_factor * 2);
  }

  // Asegurarse que la velocidad del ventilador esté dentro de los límites establecidos
  if (fan_speed > max_speed) {
    fan_speed = max_speed;
  } else if (fan_speed < min_speed) {
    fan_speed = min_speed;
  }

  return fan_speed;
}

//se modifico de modo que invierta el comportamiento por el transistor npn que alterna la señal
void setFanSpeed(float fan_speed, int fan) {
  if (fan_speed <= 0.9) {
    fan_speed = int((1 - fan_speed) * 255);
  } else fan_speed = 0;
  ledc_set_duty(speed_mode, channels[fan - 1], fan_speed);
  ledc_update_duty(speed_mode, channels[fan - 1]);
}

//se modifico de modo que invierta el comportamiento por el transistor npn que alterna la señal
void setAllFanSpeed(float fan_speed) {
  if (fan_speed <= 0.9)
    fan_speed = int((1 - fan_speed) * 255);
  else
    fan_speed = 0;

  for (int i = 0; i < 3; i++) {
    ledc_set_duty(speed_mode, channels[i], fan_speed);
    ledc_update_duty(speed_mode, channels[i]);
  }
  return;
}

void checkFans(float fans_speed) {
  if (fans_speed) {
    if (!getFanSpeed(1)) {
      setFanSpeed(0, 1);
      fan1_on = false;
    } else fan1_on = true;
    if (!getFanSpeed(2)) {
      setFanSpeed(0, 2);
      fan2_on = false;
    } else fan2_on = true;
    if (!getFanSpeed(3)) {
      setFanSpeed(0, 3);
      fan3_on = false;
    } else fan3_on = true;
  }
  return;
}

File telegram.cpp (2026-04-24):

#include "telegram.h"

#include "connection.h"
#include <HTTPClient.h>
#include <ArduinoJson.h>
#include <stdio.h>

static String s_botToken;
static String s_allowedChatId;
static int64_t s_updateOffset = 0;
static bool s_enabled = false;

static String i64ToString(int64_t v)
{
	char buf[24];
	snprintf(buf, sizeof(buf), "%lld", (long long)v);
	return String(buf);
}

static String jsonIdToString(JsonVariantConst v)
{
	if (v.is<const char *>())
	{
		const char *s = v.as<const char *>();
		return s ? String(s) : String("");
	}

	if (v.is<int64_t>())
	{
		return i64ToString(v.as<int64_t>());
	}

	if (v.is<uint64_t>())
	{
		char buf[24];
		snprintf(buf, sizeof(buf), "%llu", (unsigned long long)v.as<uint64_t>());
		return String(buf);
	}

	if (v.is<long>())
	{
		return String(v.as<long>());
	}

	if (v.is<unsigned long>())
	{
		return String(v.as<unsigned long>());
	}

	return String("");
}

static String urlEncode(const String &in)
{
	static const char *hex = "0123456789ABCDEF";
	String out;
	out.reserve(in.length() * 3);

	for (size_t i = 0; i < in.length(); i++)
	{
		const uint8_t c = (uint8_t)in[i];
		const bool safe = (c >= 'a' && c <= 'z') ||
											(c >= 'A' && c <= 'Z') ||
											(c >= '0' && c <= '9') ||
											c == '-' || c == '_' || c == '.' || c == '~';

		if (safe)
		{
			out += (char)c;
		}
		else if (c == ' ')
		{
			out += "%20";
		}
		else
		{
			out += '%';
			out += hex[(c >> 4) & 0x0F];
			out += hex[c & 0x0F];
		}
	}
	return out;
}

bool telegramInit(const char *botToken, const char *allowedChatId)
{
	s_botToken = botToken ? botToken : "";
	s_allowedChatId = allowedChatId ? allowedChatId : "";
	s_updateOffset = 0;
	s_enabled = s_botToken.length() > 0 && s_allowedChatId.length() > 0;

	if (!s_enabled)
	{
		Serial.println("telegramInit: disabled (faltan token/chat_id)");
	}
	Serial.printf("telegramInit: allowedChatId='%s'\n", s_allowedChatId.c_str());
	return s_enabled;
}

bool telegramSendMessage(const String &chatId, const String &text, bool markdown)
{
	if (!s_enabled)
		return false;

	bool ok = false;
	HTTPClient http;
	NetworkClient *client = getNetworkClient(true);
	if (client == NULL)
	{
		return false;
	}

	const String url = "https://api.telegram.org/bot" + s_botToken + "/sendMessage";
	if (http.begin(*client, url))
	{
		http.setConnectTimeout(1200);
		http.setTimeout(1500);
		http.addHeader("Content-Type", "application/x-www-form-urlencoded");

		String body = "chat_id=" + urlEncode(chatId) +
									"&text=" + urlEncode(text) +
									"&disable_web_page_preview=true";
		if (markdown)
		{
			body += "&parse_mode=Markdown";
		}

		int code = http.POST(body);
		if (code == HTTP_CODE_OK)
		{
			ok = true;
		}
		else
		{
			Serial.printf("telegramSendMessage: HTTP %d\n", code);
			Serial.println(http.getString());
		}
		http.end();
	}
	return ok;
}

bool telegramNotifyAllowed(const String &text, bool markdown)
{
	if (s_allowedChatId.length() == 0)
		return false;
	return telegramSendMessage(s_allowedChatId, text, markdown);
}

size_t telegramPollUpdates(telegram_update_t *outUpdates, size_t maxUpdates, uint32_t timeoutSeconds)
{
	if (!s_enabled || outUpdates == NULL || maxUpdates == 0)
		return 0;

	size_t parsed = 0;
	HTTPClient http;
	NetworkClient *client = getNetworkClient(true);
	if (client == NULL)
	{
		return 0;
	}

	String url = "https://api.telegram.org/bot" + s_botToken + "/getUpdates?limit=5";
	if (s_updateOffset > 0)
	{
		url += "&offset=" + i64ToString(s_updateOffset);
	}
	if (timeoutSeconds > 0)
	{
		url += "&timeout=" + String(timeoutSeconds);
	}

	if (http.begin(*client, url))
	{
		http.setConnectTimeout(1200);
		http.setTimeout(1500);
		const int code = http.GET();
		if (code == HTTP_CODE_OK)
		{
			const String payload = http.getString();
			DynamicJsonDocument doc(8192);
			DeserializationError err = deserializeJson(doc, payload);
			if (!err)
			{
				JsonArray result = doc["result"].as<JsonArray>();
				for (JsonVariant v : result)
				{
					if (parsed >= maxUpdates)
						break;

					const int64_t updateId = v["update_id"].as<int64_t>();
					JsonVariant msg = v["message"];
					if (msg.isNull())
					{
						if (updateId >= s_updateOffset)
							s_updateOffset = updateId + 1;
						continue;
					}

					const String chatId = jsonIdToString(msg["chat"]["id"]);
					const String text = msg["text"] | "";
					if (chatId.length() == 0 || text.length() == 0)
					{
						if (updateId >= s_updateOffset)
							s_updateOffset = updateId + 1;
						continue;
					}

					outUpdates[parsed].update_id = updateId;
					outUpdates[parsed].chat_id = chatId;
					outUpdates[parsed].from_id = jsonIdToString(msg["from"]["id"]);
					outUpdates[parsed].username = msg["from"]["username"] | "";
					outUpdates[parsed].text = text;
					parsed++;

					if (updateId >= s_updateOffset)
						s_updateOffset = updateId + 1;
				}
			}
			else
			{
				Serial.print("telegramPollUpdates: JSON error: ");
				Serial.println(err.c_str());
			}
		}
		else
		{
			Serial.printf("telegramPollUpdates: HTTP %d\n", code);
		}
		http.end();
	}
	return parsed;
}

void telegramSetOffset(int64_t offset)
{
	s_updateOffset = offset;
}

int64_t telegramGetOffset()
{
	return s_updateOffset;
}

bool telegramParseCommand(const telegram_update_t &upd, String &command, String &args)
{
	command = "";
	args = "";

	String txt = upd.text;
	txt.trim();
	if (txt.length() == 0 || txt[0] != '/')
		return false;

	int sp = txt.indexOf(' ');
	if (sp < 0)
	{
		command = txt;
		return true;
	}

	command = txt.substring(0, sp);
	args = txt.substring(sp + 1);
	args.trim();
	return true;
}

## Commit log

2026-02-19 chore: compile in new version of esp32 lib
2026-03-02 fix: test EthernetENC with correct module
    [connection.cpp]
2026-03-11 chore: make schematic
    [ESP32-DEVKIT-V1.step, rack_monitor_pcb.kicad_pcb, rack_monitor_pcb.kicad_sch]
2026-03-11 fix: endpoints for EthernetClient
    [connection.cpp, data_parser.cpp, rack-controller-firmware.ino]
2026-03-31 chore: fix http comunication via WiFi tested
    [data_parser.cpp, global_variables.h, rack-controller-firmware.ino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]
